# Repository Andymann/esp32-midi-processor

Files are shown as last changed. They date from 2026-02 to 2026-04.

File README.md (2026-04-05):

# esp32-midi-processor

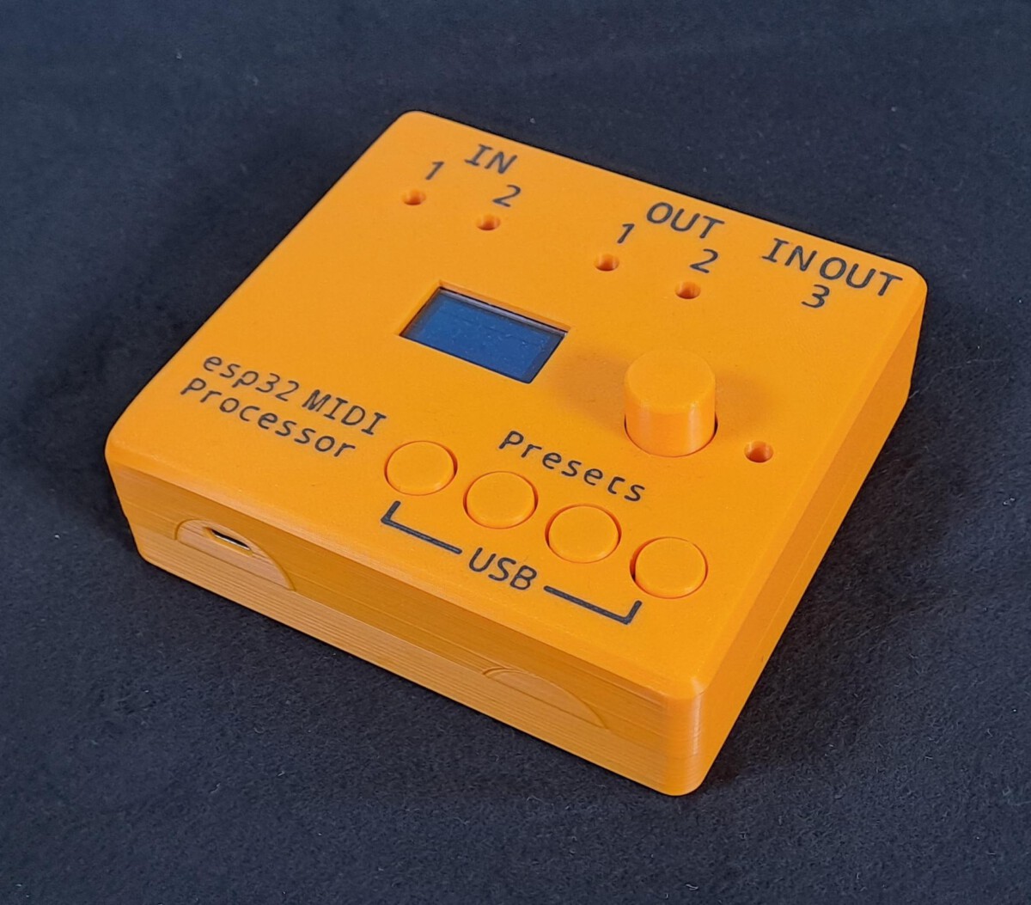
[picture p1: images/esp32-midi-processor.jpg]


esp32-based multitool. Routing, merging, realtime-manipulation of MIDI-data.  
This repo contains code, kicad-files and a BOM for (nearly) one-click order at [pcbway](https://https://pcbway-com).  

Find more details on the project, instructions on how to order your own pcbs and more at https://andyland.info/wordpress/esp32-midi-processor/

If you directly want to order your set of PCBs for this project feel free to

<p style="text-align:center; <a href="https://www.pcbway.com/project/shareproject/esp32_Midi_Prodessor_1403f10f.html">PCB from PCBWay</a></p>

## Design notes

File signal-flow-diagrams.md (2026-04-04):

# ESP32 MIDI Processor — Signal Flow Diagrams

## 1. Top-Level Signal Flow

```mermaid
flowchart LR
    IN1["MIDI In 1\n(Serial1 / UART)"]
    IN2["MIDI In 2\n(Serial2 / UART)"]
    IN3["USB MIDI In\n(MAX3421E Host)"]

    R1["Routing In1\n(None/1/2/3/1+2/1+3/2+3/All)"]
    R2["Routing In2\n(None/1/2/3/1+2/1+3/2+3/All)"]
    R3["Routing In3\n(None/1/2/1+2)"]

    P1["Output 1\nProcessing Pipeline"]
    P2["Output 2\nProcessing Pipeline"]
    P3["USB Output\nProcessing Pipeline"]

    OUT1["MIDI Out 1\n(Serial1 / UART)"]
    OUT2["MIDI Out 2\n(Serial2 / UART)"]
    OUT3["USB MIDI Out\n(MAX3421E Host)"]

    IN1 --> R1
    IN2 --> R2
    IN3 --> R3

    R1 -->|"to Out1"| P1
    R1 -->|"to Out2"| P2
    R1 -->|"to USB"| P3

    R2 -->|"to Out1"| P1
    R2 -->|"to Out2"| P2
    R2 -->|"to USB"| P3

    R3 -->|"to Out1"| P1
    R3 -->|"to Out2"| P2

    P1 --> OUT1
    P2 --> OUT2
    P3 --> OUT3
```

> **Note:** USB In (In3) cannot be routed back to USB Out — only to Out1, Out2, or both.

---

## 2. Per-Output Processing Pipeline

Each of the three outputs has an independent processing pipeline applied to every MIDI message routed to it.

```mermaid
flowchart TD
    A["Incoming MIDI packet\n(from routing)"]
    B["Velocity Modifier\n(passthru / fix 63,100,127 / random / random-100)\nNote On/Off only"]
    C["Note Channel Remap\n(passthru or Ch 1–16)\nNote On/Off only"]
    D["CC Channel Remap\n(passthru or Ch 1–16)\nCC messages only"]
    E["Scale Filter\n(passthru / Major / Minor /\nPentatonic Maj / Pentatonic Min)\nNote On/Off only — drop if out of scale"]
    F["Clock Filter\n(pass all / block clock / clock only)"]
    G{"drop flag set?"}
    H["Send to Output\n(Serial1 / Serial2 / USB)"]
    X["Discard"]

    A --> B --> C --> D --> E --> F --> G
    G -->|"no"| H
    G -->|"yes"| X
```

---

## 3. Routing Options Matrix

Each input has an independent routing setting. The table below lists all values.

```mermaid
flowchart LR
    subgraph "Routing values"
        direction TB
        NONE["None — dropped"]
        TO1["→ Out 1 only"]
        TO2["→ Out 2 only"]
        TO3["→ USB only"]
        TO12["→ Out 1 + Out 2"]
        TO13["→ Out 1 + USB"]
        TO23["→ Out 2 + USB"]
        TO123["→ Out 1 + Out 2 + USB"]
    end

    subgraph "Input 1  (full set)"
        I1(In 1) --> NONE & TO1 & TO2 & TO3 & TO12 & TO13 & TO23 & TO123
    end

    subgraph "Input 2  (full set)"
        I2(In 2) --> NONE2["None"] & TO1b["→ Out 1"] & TO2b["→ Out 2"] & TO3b["→ USB"] & TO12b["→ Out 1+2"] & TO13b["→ Out 1+USB"] & TO23b["→ Out 2+USB"] & TO123b["→ All"]
    end

    subgraph "Input 3 / USB  (limited)"
        I3(USB In) --> NONE3["None"] & TO1c["→ Out 1"] & TO2c["→ Out 2"] & TO12c["→ Out 1+2"]
    end
```

---

## 4. Per-Output Modifier Details

```mermaid
flowchart TD
    subgraph "Velocity  (Note On only)"
        V0[Passthru]
        V1[Fix 63]
        V2[Fix 100]
        V3[Fix 127]
        V4[Random 0–127]
        V5[Random 91–110]
    end

    subgraph "Scale Filter  (Note On/Off only)"
        S0[Passthru — all notes pass]
        S1[Major scale]
        S2[Natural Minor scale]
        S3[Pentatonic Major]
        S4[Pentatonic Minor]
        SN[Root Note: C C# D D# E F F# G G# A A# B]
    end

    subgraph "Channel Remap"
        C0[Note Ch: passthru or 1–16]
        C1[CC Ch: passthru or 1–16]
    end

    subgraph "Clock Filter"
        F0[Pass All — default]
        F1[Block Clock — drop F8/FA/FC]
        F2[Clock Only — pass only F8/FA/FC]
    end
```

---

## 5. MIDI Queue / Processing Order

```mermaid
sequenceDiagram
    participant HW1 as Serial1 (In 1)
    participant HW2 as Serial2 (In 2)
    participant USB as USB MIDI (In 3)
    participant Q  as MIDI Queue (FIFO, 10 slots)
    participant SP as sendPacket()
    participant O1 as Out 1
    participant O2 as Out 2
    participant O3 as USB Out

    loop Every loop()
        HW1->>Q: push (source=1)
        HW2->>Q: push (source=2)
        USB->>Q: push (source=3)
        Q->>SP: pop & process in order
        SP->>SP: apply routing
        SP->>SP: velocity / channel / scale / clock filter (per output)
        SP->>O1: write if routed
        SP->>O2: write if routed
        SP->>O3: send if routed
    end
```

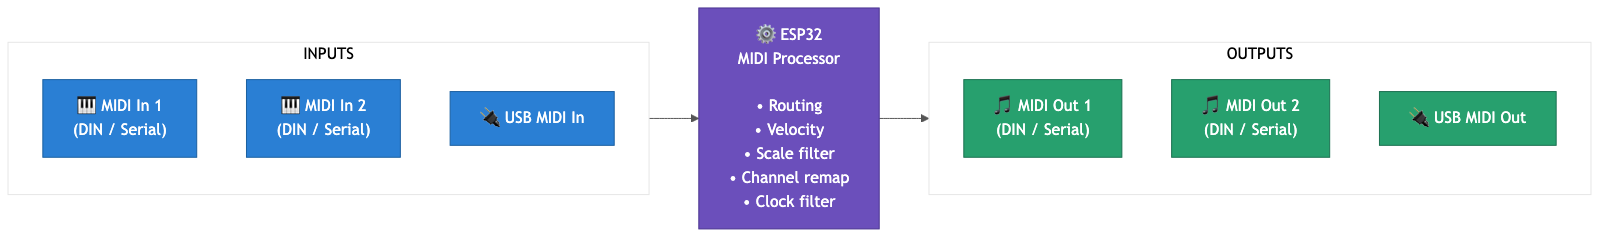
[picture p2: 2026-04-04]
diagrams/simple-01-overview.png

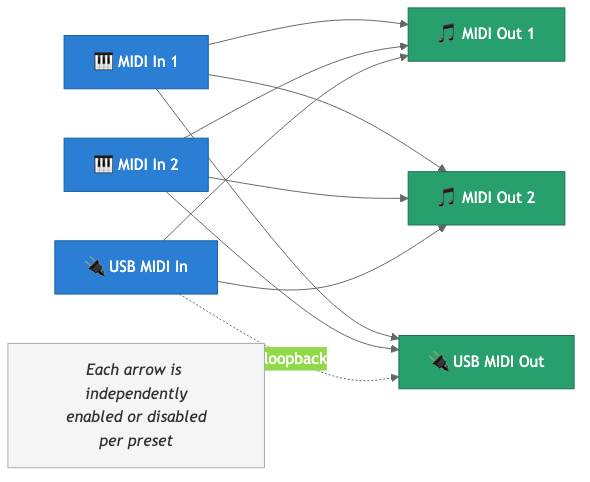
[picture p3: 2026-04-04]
diagrams/simple-02-routing.png

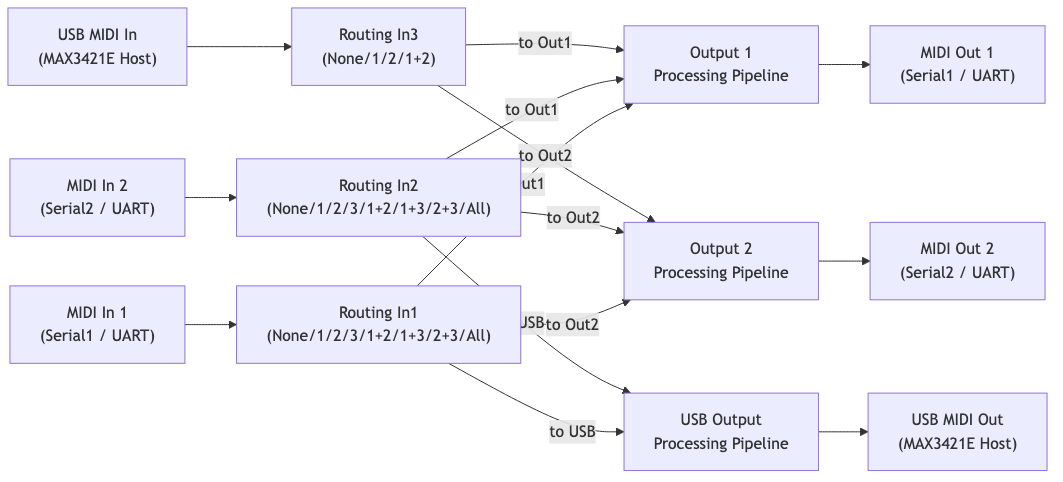
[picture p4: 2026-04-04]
diagrams/01-top-level.png

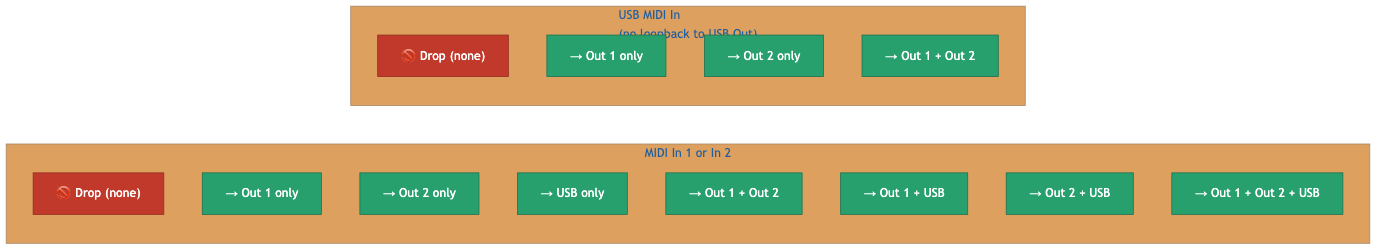
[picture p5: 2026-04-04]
diagrams/simple-04-routing-options.png

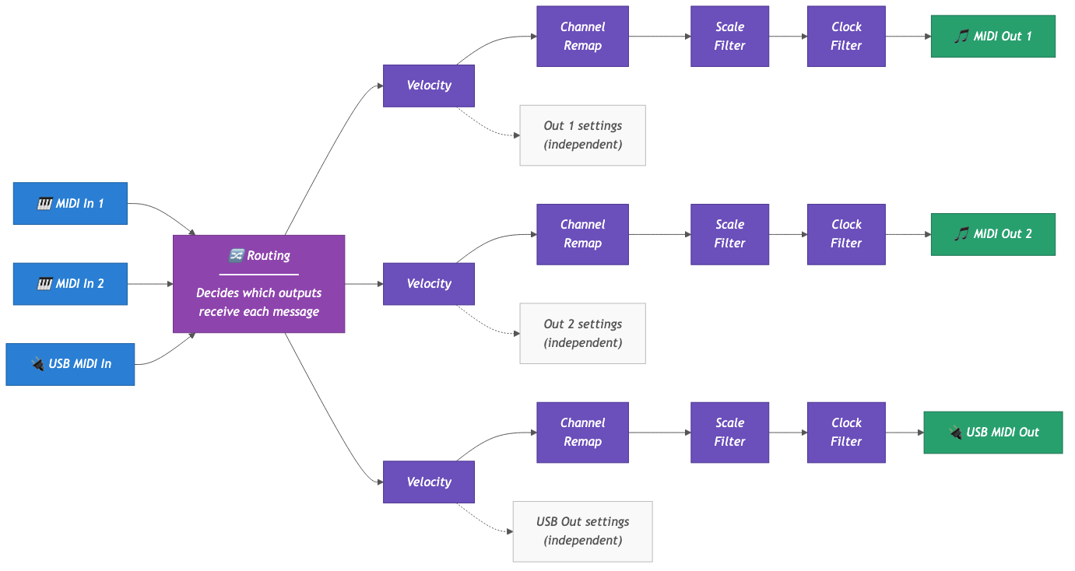
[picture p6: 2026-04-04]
diagrams/simple-05-per-output-processing.png

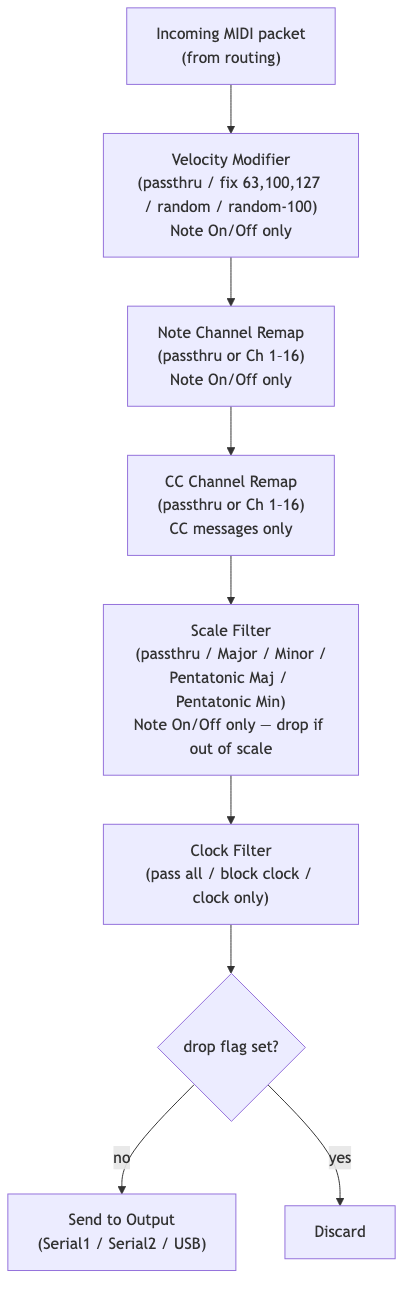
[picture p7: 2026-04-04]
diagrams/02-processing-pipeline.png

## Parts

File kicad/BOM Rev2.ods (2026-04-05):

Item # | *Designator | *Qty | Manufacturer | *Mfg Part # | Description / Value | *Package/Footprint | *Unit Price(5 sets) | *Total | *Delivery Time | *Actual Purchase Mfg Part # | *PCBWay Note | Customer Reply | PCBWay Update
1 | R9,R7 | 2 | Vishay/ Dale | CRCW060333R0JNEA | 33 | R_0603_1608Metric
2 | R3,R6 | 2 | Vishay/ Dale | CRCW06034K70JNEAC | 4k7 | R_0603_1608Metric
3 | R11 | 1 | Vishay/ Dale | CRCW0603330RJNEAC | 330 | R_0603_1608Metric
4 | D5,D4,D3,D7,D6 | 5 | Fetzek | FZ2812-5050 | 2812 addressable RGB LED | LED_SMD:LED_WS2812B_PLCC4_5.0x5.0mm_P3.2mm
5 | R5,R2 | 2 | Vishay/ Dale | CRCW0603470RJNEAC | 470 | R_0603_1608Metric
6 | R15,R16,R14,R12,R13 | 5 | Vishay/ Dale | CRCW060310K0JNEA | 10k | R_0603_1608Metric
7 | C1, C2, C3,C4,C7,C6,C5 | 7 | Kemet | C0603C104K1RACTU | 0.1µ | C_0603_1608Metric
8 | U1,U2 | 2 | Lite-on | 6N138S-TA1 | 6N138
9 | R8,R10 | 2 | Vishay/ Dale | CRCW060310R0JNEA | 10 | R_0603_1608Metric
10 | D1,D2 | 2 | Onsemi | 1N4148WT | 1N4148WT | SOD123
11 | R4,R1 | 2 | Vishay/ Dale | CRCW0603220RJNEAHP | 220 | R_0603_1608Metric
12 | J1, J2, J3, J4 | 4 | CUI Devices | SJ-3523-SMT-TR |  | Jack_3.5mm_CUI_SJ-3523-SMT_Horizontal
13 | J7 | 0 | not used
14 | J12 | 0 | not used
15 | J8 | 0 | not used
16 | J5 | 0 | not used
17 | U3 | 0 | not used
18 | SW5 | 0 | not used
19 | J6 | 0 | not used
20 | J10 | 0 | not used
21 | J13 | 0 | not used
22 | SW2,SW1,SW3,SW4 | 0 | not used
23 | J9 | 0 | not used

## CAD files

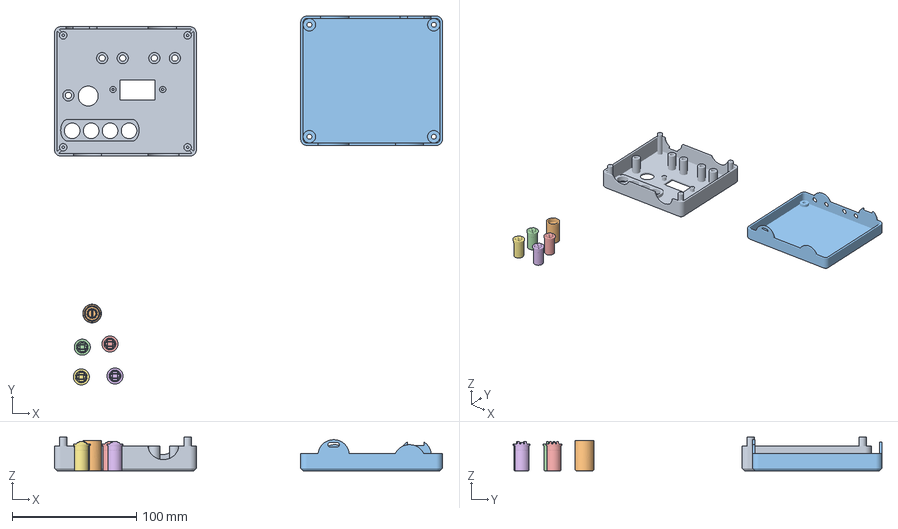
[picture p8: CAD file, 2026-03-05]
esp32 Midi Processor.3mf
311.9 x 296.5 x 27.0 mm
Assembly
esp32 Midi Processor Case Rev 14 Buttons (1).stl
esp32 Midi Processor Case Rev 13.stl
esp32 Midi Processor Case Rev 14 Buttons.stl_1
esp32 Midi Processor Case Rev 14 Buttons.stl_2
esp32 Midi Processor Case Rev 14 Buttons.stl_3
esp32 Midi Processor Case Rev 14 Buttons.stl_4

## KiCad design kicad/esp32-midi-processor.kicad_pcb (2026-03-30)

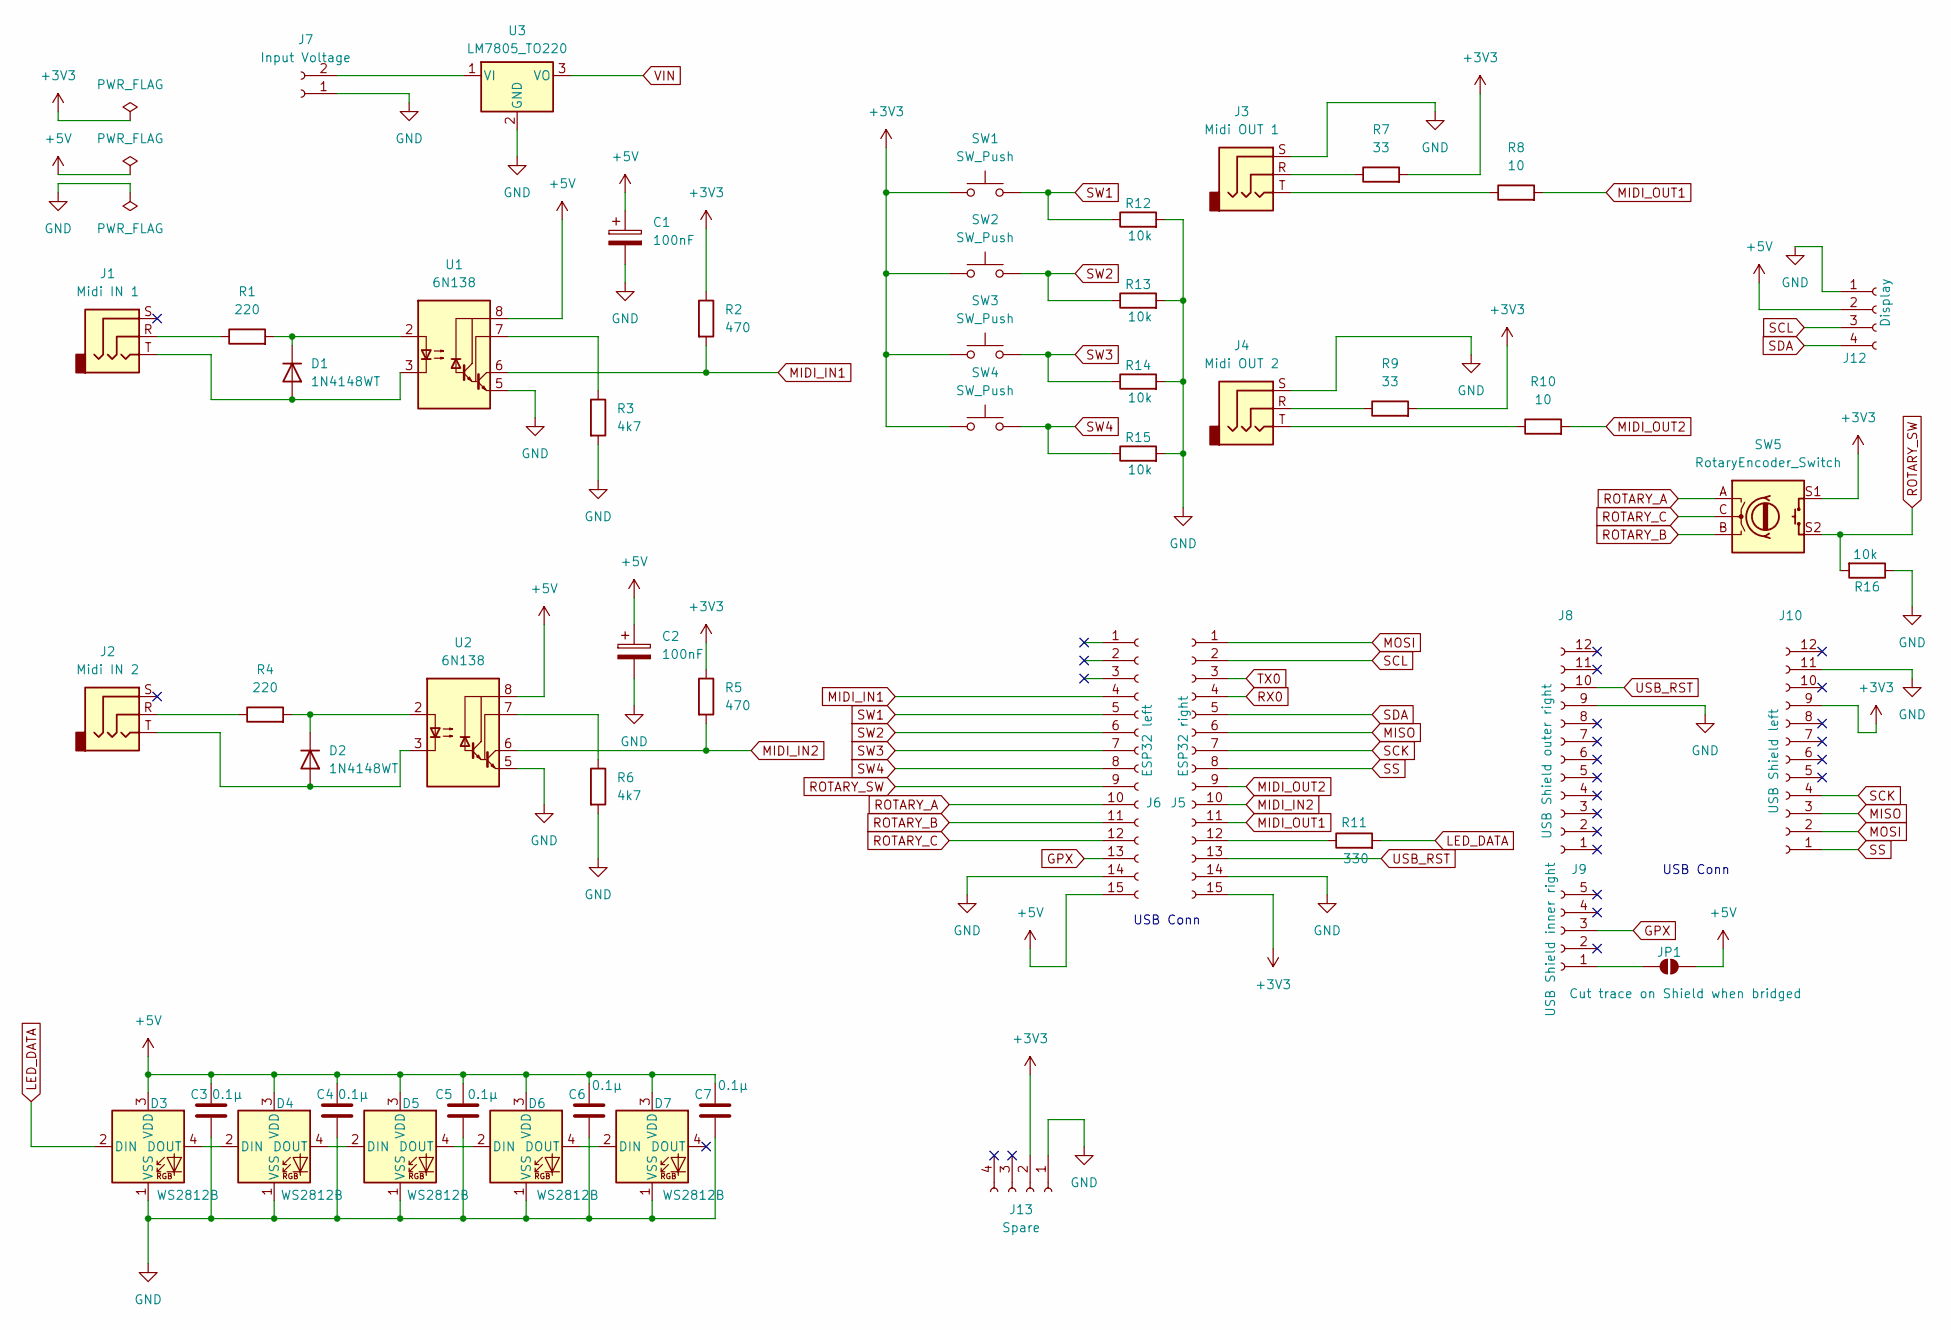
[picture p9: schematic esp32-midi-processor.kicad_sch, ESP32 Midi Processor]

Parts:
C1, C2: 100nF; C_0603_1608Metric
C3, C4, C5, C6, C7: 0.1µ; C_0603_1608Metric
D1, D2: 1N4148WT; D_SOD-523
D3, D4, D5, D6, D7: WS2812B; LED_WS2812B_PLCC4_5.0x5.0mm_P3.2mm
J1: Midi IN 1; Jack_3.5mm_CUI_SJ-3523-SMT_Horizontal
J2: Midi IN 2; Jack_3.5mm_CUI_SJ-3523-SMT_Horizontal
J3: Midi OUT 1; Jack_3.5mm_CUI_SJ-3523-SMT_Horizontal
J4: Midi OUT 2; Jack_3.5mm_CUI_SJ-3523-SMT_Horizontal
J5: ESP32 right; PinHeader_1x15_P2.54mm_Vertical
J6: ESP32 left; PinHeader_1x15_P2.54mm_Vertical
J7: Input Voltage; TerminalBlock_RND_205-00001_1x02_P5.00mm_Horizontal
J8: USB Shield outer right; PinHeader_1x12_P2.54mm_Vertical
J9: USB Shield inner right; PinHeader_1x05_P2.54mm_Vertical
J10: USB Shield left; PinHeader_1x12_P2.54mm_Vertical
J12: Display; PinHeader_1x04_P2.54mm_Vertical
J13: Spare; PinHeader_1x04_P2.54mm_Vertical
JP1: Cut trace on Shield when bridged; SolderJumper-2_P1.3mm_Open_RoundedPad1.0x1.5mm
R1, R4: 220; R_0603_1608Metric
R2, R5: 470; R_0603_1608Metric
R3, R6: 4k7; R_0603_1608Metric
R7, R9: 33; R_0603_1608Metric
R8, R10: 10; R_0603_1608Metric
R11: 330; R_0603_1608Metric
R12, R13, R14, R15, R16: 10k; R_0603_1608Metric
SW1, SW2, SW3, SW4: SW_Push; SW_PUSH-12mm_Wuerth-430476085716
SW5: RotaryEncoder_Switch; RotaryEncoder_Alps_EC11E-Switch_Vertical_H20mm
U1, U2: 6N138; SOP-8_6.605x9.655mm_P2.54mm
U3: LM7805_TO220; TO-220-3_Vertical

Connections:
+3V3: J5.15, J10.9, J13.2, R2.1, R5.1, R7.2, R9.2, SW1.1, SW2.1, SW3.1, SW4.1, SW5.S1
+5V: C1.1, C2.1, C3.1, C4.1, C5.1, C6.1, C7.1, D3.3 (VDD), D4.3 (VDD), D5.3 (VDD), D6.3 (VDD), D7.3 (VDD), J6.15, J12.2, JP1.2 (B), U1.8 (VCC), U2.8 (VCC)
GND: C1.2, C2.2, C3.2, C4.2, C5.2, C6.2, C7.2, D3.1 (VSS), D4.1 (VSS), D5.1 (VSS), D6.1 (VSS), D7.1 (VSS), J3.S, J4.S, J5.14, J6.14, J7.1, J8.9, J10.11, J12.1, J13.1, R3.2, R6.2, R12.2, R13.2, R14.2, R15.2, R16.1, U1.5 (GND), U2.5 (GND), U3.2 (GND)
GPX: J6.13, J9.3
LED_DATA: D3.2 (DIN), R11.2
MIDI_IN1: J6.4, R2.2, U1.6 (VO2)
MIDI_IN2: J5.10, R5.2, U2.6 (VO2)
MIDI_OUT1: J5.11, R8.2
MIDI_OUT2: J5.9, R10.2
MISO: J5.6, J10.3
MOSI: J5.1, J10.2
unnamed: D1.2 (A), J1.T, U1.3 (C2)
unnamed: D1.1 (K), R1.2, U1.2 (C1)
unnamed: D2.2 (A), J2.T, U2.3 (C2)
unnamed: D2.1 (K), R4.2, U2.2 (C1)
unnamed: D3.4 (DOUT), D4.2 (DIN)
unnamed: D4.4 (DOUT), D5.2 (DIN)
unnamed: D5.4 (DOUT), D6.2 (DIN)
unnamed: D6.4 (DOUT), D7.2 (DIN)
unnamed: J1.R, R1.1
unnamed: J2.R, R4.1
unnamed: J3.R, R7.1
unnamed: J3.T, R8.1
unnamed: J4.R, R9.1
unnamed: J4.T, R10.1
unnamed: J5.12, R11.1
unnamed: J7.2, U3.1 (VI)
unnamed: J9.1, JP1.1 (A)
unnamed: R3.1, U1.7 (VO1)
unnamed: R6.1, U2.7 (VO1)
ROTARY_A: J6.10, SW5.A
ROTARY_B: J6.11, SW5.B
ROTARY_C: J6.12, SW5.C
ROTARY_SW: J6.9, R16.2, SW5.S2
RX0: J5.4
SCK: J5.7, J10.4
SCL: J5.2, J12.3
SDA: J5.5, J12.4
SS: J5.8, J10.1
SW1: J6.5, R12.1, SW1.2
SW2: J6.6, R13.1, SW2.2
SW3: J6.7, R14.1, SW3.2
SW4: J6.8, R15.1, SW4.2
TX0: J5.3
USB_RST: J5.13, J8.10
VIN: U3.3 (VO)

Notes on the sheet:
USB Conn

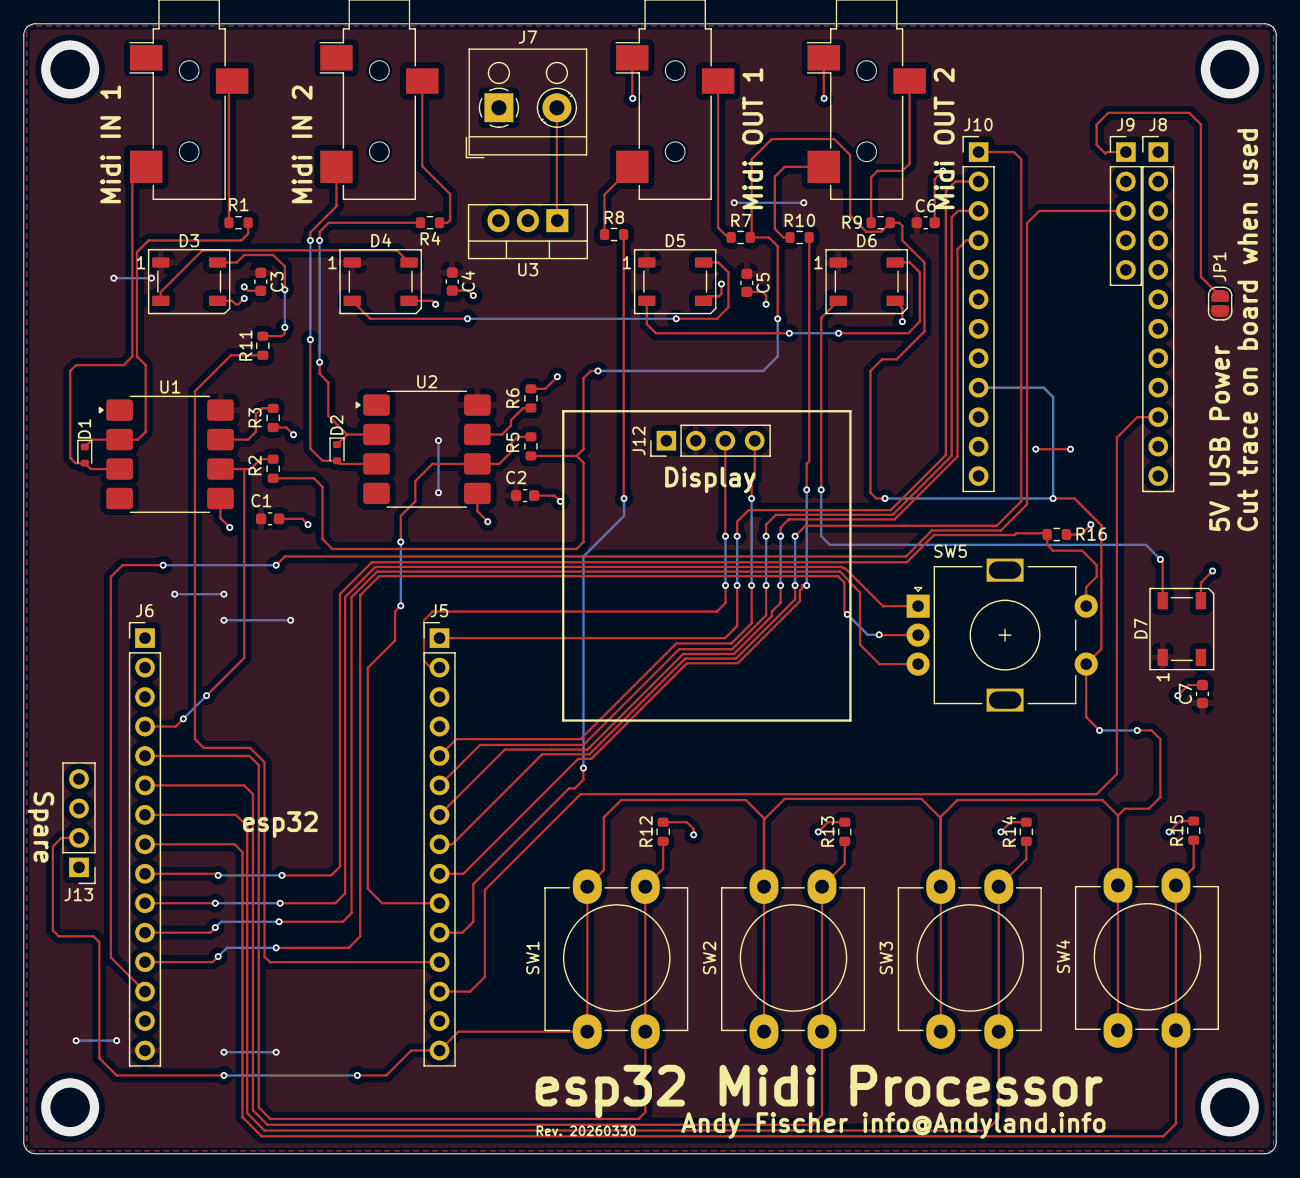
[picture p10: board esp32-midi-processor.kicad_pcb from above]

Board: 2 copper layers, 108.0 x 97.4 mm, 51 parts (0 on the bottom side), 43 nets.

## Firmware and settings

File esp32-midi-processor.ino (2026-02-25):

/*
    esp32 Midi Processor
*/
#include <HardwareSerial.h>
#include <Adafruit_NeoPixel.h>
#include <SPI.h>
#include <Wire.h>
#include <Adafruit_GFX.h>
#include <Adafruit_SSD1306.h>
#include <ESP32Encoder.h> // https://github.com/madhephaestus/ESP32Encoder.git 
#include <usbh_midi.h>
#include <usbhub.h>
#include <AbleButtons.h>
#include "AppFeature.h"
#include <Fonts/FreeSans9pt7b.h>
#include <Fonts/FreeSans24pt7b.h>
#include <BlockNot.h>
#include <EEPROM.h>

#define VERSION "0.98"

#define PRESET_COUNT 4
#define EEPROM_SIZE  (2 + PRESET_COUNT * (1 + sizeof(AppSettings)))

// Declaration for SSD1306 display connected using I2C
#define SCREEN_WIDTH 128  // OLED display width, in pixels
#define SCREEN_HEIGHT 64  // OLED display height, in pixels
#define OLED_RESET -1  // Reset pin # (or -1 if sharing Arduino reset pin)
#define SCREEN_ADDRESS 0x3C
Adafruit_SSD1306 display(SCREEN_WIDTH, SCREEN_HEIGHT, &Wire, OLED_RESET);

#define NUM_LEDS 5
#define LED_DATA_PIN 2
#define LED_OFF 0
#define LED_ON 10
Adafruit_NeoPixel pixels(NUM_LEDS, LED_DATA_PIN, NEO_GRB + NEO_KHZ800);

// Serial
#define RXD2 16
#define TXD2 17
#define TXD1 4
#define RXD1 34

// Rotary
#define CLK 14 // CLK ENCODER 
#define ENC_C 27
#define DT 12 // DT ENCODER 
ESP32Encoder encoder;
int64_t iEncoderLast=0;

#define MIDI_CLOCK 0xF8
#define MIDI_START 0xFA
#define MIDI_STOP 0xFC

// USB
USB Usb;
USBHub Hub(&Usb);
USBH_MIDI  Midi(&Usb);
#define MAX_RESET 15 //MAX3421E pin 12
#define MAX_GPX   13 //MAX3421E pin 17


using Button = AblePulldownClickerButton;

Button btnA(35);
Button btnB(32);
Button btnC(33);
Button btnD(25);
Button btnEnc(26);

BlockNot tmrIn1(50); //In Milliseconds 
BlockNot tmrIn2(50);
BlockNot tmrOut1(50);
BlockNot tmrOut2(50);
BlockNot tmrUSB(50);
BlockNot tmrDisplay(3000);

bool bBtnA_Reset = false;
bool bBtnB_Reset = false;
bool bBtnC_Reset = false;
bool bBtnD_Reset = false;
bool bBtnEnc_Reset = false;

bool bBtnA_old = false;
bool bBtnB_old = false;
bool bBtnC_old = false;
bool bBtnD_old = false;
bool bBtnEnc_old = false;

bool btnA_Held = false;
bool btnB_Held = false;
bool btnC_Held = false;
bool btnD_Held = false;
bool btnEnc_Held = false;
bool bBtnAD_ComboActive = false;  // A+D held: skip preset save, allow Usb.Init 
// Input packet with data and drop flag (replaces using 3rd byte 0xFF as sentinel)
struct MidiPacket {
  uint8_t data[3];
  bool drop;  // true = no data / do not send (filtered or already consumed)
};

// Queue: up to 10 incoming MIDI events, processed in order (FIFO)
#define MIDI_QUEUE_SIZE 10
struct QueuedMidiEvent {
  MidiPacket pkt;
  uint8_t source;  // 1, 2, or 3 for input 1, 2, USB
};
static QueuedMidiEvent midiQueue[MIDI_QUEUE_SIZE];
static uint8_t queueHead = 0;  // next write
static uint8_t queueTail = 0;  // next read
static uint8_t queueCount = 0;

static bool pushMidiQueue(const MidiPacket *pkt, uint8_t source) {
  if (queueCount >= MIDI_QUEUE_SIZE) return false;
  midiQueue[queueHead].pkt = *pkt;
  midiQueue[queueHead].pkt.drop = false;
  midiQueue[queueHead].source = source;
  queueHead = (queueHead + 1) % MIDI_QUEUE_SIZE;
  queueCount++;
  return true;
}
static bool popMidiQueue(QueuedMidiEvent *out) {
  if (queueCount == 0) return false;
  *out = midiQueue[queueTail];
  queueTail = (queueTail + 1) % MIDI_QUEUE_SIZE;
  queueCount--;
  return true;
}

MidiPacket midiPacket_IN1 = { {0xFF, 0xFF, 0xFF}, true };
MidiPacket midiPacket_IN2 = { {0xFF, 0xFF, 0xFF}, true };
MidiPacket midiPacket_IN3 = { {0xFF, 0xFF, 0xFF}, true };
uint8_t iCounter_IN1 = 0;
uint8_t iCounter_IN2 = 0;


AppFeature arrFeatures[] = {
  AppFeature("Route 1-x", 0, FEATURE_GROUP_ROUTING_IN_1, ROUTING_TO_NONE),
  AppFeature("Route 1-1", 0, FEATURE_GROUP_ROUTING_IN_1, ROUTING_TO_1, true),
  AppFeature("Route 1-2", 0, FEATURE_GROUP_ROUTING_IN_1, ROUTING_TO_2),
  AppFeature("Route 1-3", 0, FEATURE_GROUP_ROUTING_IN_1, ROUTING_TO_3),
  AppFeature("Route 1-1,2", 0, FEATURE_GROUP_ROUTING_IN_1, ROUTING_TO_12),
  AppFeature("Route 1-1,3", 0, FEATURE_GROUP_ROUTING_IN_1, ROUTING_TO_13),
  AppFeature("Route 1-2,3", 0, FEATURE_GROUP_ROUTING_IN_1, ROUTING_TO_23),
  AppFeature("Route 1-All", 0, FEATURE_GROUP_ROUTING_IN_1, ROUTING_TO_123),

  AppFeature("Route 2-x", 0, FEATURE_GROUP_ROUTING_IN_2, ROUTING_TO_NONE, true),
  AppFeature("Route 2-1", 0, FEATURE_GROUP_ROUTING_IN_2, ROUTING_TO_1),
  AppFeature("Route 2-2", 0, FEATURE_GROUP_ROUTING_IN_2, ROUTING_TO_2),
  AppFeature("Route 2-3", 0, FEATURE_GROUP_ROUTING_IN_2, ROUTING_TO_3),
  AppFeature("Route 2-1,2", 0, FEATURE_GROUP_ROUTING_IN_2, ROUTING_TO_12),
  AppFeature("Route 2-1,3", 0, FEATURE_GROUP_ROUTING_IN_2, ROUTING_TO_13),
  AppFeature("Route 2-2,3", 0, FEATURE_GROUP_ROUTING_IN_2, ROUTING_TO_23),
  AppFeature("Route 2-All", 0, FEATURE_GROUP_ROUTING_IN_2, ROUTING_TO_123),

  AppFeature("Route 3-x", 0, FEATURE_GROUP_ROUTING_IN_3, ROUTING_TO_NONE, true),
  AppFeature("Route 3-1", 0, FEATURE_GROUP_ROUTING_IN_3, ROUTING_TO_1),
  AppFeature("Route 3-2", 0, FEATURE_GROUP_ROUTING_IN_3, ROUTING_TO_2),
  //AppFeature("Route 3-3", 0, FEATURE_GROUP_ROUTING_IN_3, ROUTING_3_TO_3),
  AppFeature("Route 3-1,2", 0, FEATURE_GROUP_ROUTING_IN_3, ROUTING_TO_12),
  //AppFeature("Route 3-1,3", 0, FEATURE_GROUP_ROUTING_IN_3, ROUTING_3_TO_13),
  //AppFeature("Route 3-2,3", 0, FEATURE_GROUP_ROUTING_IN_3, ROUTING_3_TO_23),
  //AppFeature("Route 3-All", 0, FEATURE_GROUP_ROUTING_IN_3, ROUTING_3_TO_123),

  AppFeature("1 Vel PT", 1, FEATURE_GROUP_VELOCITY, VELOCITY_PASSTHRU, true),
  AppFeature("1 Vel Fix63", 1, FEATURE_GROUP_VELOCITY, VELOCITY_FIX_63),
  AppFeature("1 Vel Fix100", 1, FEATURE_GROUP_VELOCITY, VELOCITY_FIX_100),
  AppFeature("1 Vel Fix127", 1, FEATURE_GROUP_VELOCITY, VELOCITY_FIX_127),
  AppFeature("1 Vel Rnd", 1, FEATURE_GROUP_VELOCITY, VELOCITY_RANDOM),
  AppFeature("1 Vel Rnd100", 1, FEATURE_GROUP_VELOCITY, VELOCITY_RANDOM_100),

  AppFeature("1 Scale PT", 1, FEATURE_GROUP_SCALE, SCALE_PASSTHRU, true),
  AppFeature("1 Scale Maj", 1, FEATURE_GROUP_SCALE, SCALE_MAJOR),
  AppFeature("1 Scale Min", 1, FEATURE_GROUP_SCALE, SCALE_MINOR),
  AppFeature("1 Scale 5Maj", 1, FEATURE_GROUP_SCALE, SCALE_PENTATONIC_MAJOR),
  AppFeature("1 Scale 5Min", 1, FEATURE_GROUP_SCALE, SCALE_PENTATONIC_MINOR),

  AppFeature("1 Root None", 1, FEATURE_GROUP_ROOTNOTE, ROOTNOTE_PASSTHROUGH, true),
  AppFeature("1 Root C", 1, FEATURE_GROUP_ROOTNOTE, ROOTNOTE_C),
  AppFeature("1 Root C#", 1, FEATURE_GROUP_ROOTNOTE, ROOTNOTE_Cs),
  AppFeature("1 Root D", 1, FEATURE_GROUP_ROOTNOTE, ROOTNOTE_D),
  AppFeature("1 Root D#", 1, FEATURE_GROUP_ROOTNOTE, ROOTNOTE_Ds),
  AppFeature("1 Root E", 1, FEATURE_GROUP_ROOTNOTE, ROOTNOTE_E),
  AppFeature("1 Root F", 1, FEATURE_GROUP_ROOTNOTE, ROOTNOTE_F),
  AppFeature("1 Root F#", 1, FEATURE_GROUP_ROOTNOTE, ROOTNOTE_Fs),
  AppFeature("1 Root G", 1, FEATURE_GROUP_ROOTNOTE, ROOTNOTE_G),
  AppFeature("1 Root G#", 1, FEATURE_GROUP_ROOTNOTE, ROOTNOTE_Gs),
  AppFeature("1 Root A", 1, FEATURE_GROUP_ROOTNOTE, ROOTNOTE_A),
  AppFeature("1 Root A#", 1, FEATURE_GROUP_ROOTNOTE, ROOTNOTE_As),
  AppFeature("1 Root H", 1, FEATURE_GROUP_ROOTNOTE, ROOTNOTE_H),

  AppFeature("1 Note Ch PT", 1, FEATURE_GROUP_NOTE_CHANNEL, CHANNEL_PASSTHRU, true),
  AppFeature("1 Note Ch 1", 1, FEATURE_GROUP_NOTE_CHANNEL, CHANNEL_1),
  AppFeature("1 Note Ch 2", 1, FEATURE_GROUP_NOTE_CHANNEL, CHANNEL_2),
  AppFeature("1 Note Ch 3", 1, FEATURE_GROUP_NOTE_CHANNEL, CHANNEL_3),
  AppFeature("1 Note Ch 4", 1, FEATURE_GROUP_NOTE_CHANNEL, CHANNEL_4),
  AppFeature("1 Note Ch 5", 1, FEATURE_GROUP_NOTE_CHANNEL, CHANNEL_5),
  AppFeature("1 Note Ch 6", 1, FEATURE_GROUP_NOTE_CHANNEL, CHANNEL_6),
  AppFeature("1 Note Ch 7", 1, FEATURE_GROUP_NOTE_CHANNEL, CHANNEL_7),
  AppFeature("1 Note Ch 8", 1, FEATURE_GROUP_NOTE_CHANNEL, CHANNEL_8),
  AppFeature("1 Note Ch 9", 1, FEATURE_GROUP_NOTE_CHANNEL, CHANNEL_9),
  AppFeature("1 Note Ch 10", 1, FEATURE_GROUP_NOTE_CHANNEL, CHANNEL_10),
  AppFeature("1 Note Ch 11", 1, FEATURE_GROUP_NOTE_CHANNEL, CHANNEL_11),
  AppFeature("1 Note Ch 12", 1, FEATURE_GROUP_NOTE_CHANNEL, CHANNEL_12),
  AppFeature("1 Note Ch 13", 1, FEATURE_GROUP_NOTE_CHANNEL, CHANNEL_13),
  AppFeature("1 Note Ch 14", 1, FEATURE_GROUP_NOTE_CHANNEL, CHANNEL_14),
  AppFeature("1 Note Ch 15", 1, FEATURE_GROUP_NOTE_CHANNEL, CHANNEL_15),
  AppFeature("1 Note Ch 16", 1, FEATURE_GROUP_NOTE_CHANNEL, CHANNEL_16),

  AppFeature("1 CC Ch PT", 1, FEATURE_GROUP_CC_CHANNEL, CHANNEL_PASSTHRU, true),
  AppFeature("1 CC Ch 1", 1, FEATURE_GROUP_CC_CHANNEL, CHANNEL_1),
  AppFeature("1 CC Ch 2", 1, FEATURE_GROUP_CC_CHANNEL, CHANNEL_2),
  AppFeature("1 CC Ch 3", 1, FEATURE_GROUP_CC_CHANNEL, CHANNEL_3),
  AppFeature("1 CC Ch 4", 1, FEATURE_GROUP_CC_CHANNEL, CHANNEL_4),
  AppFeature("1 CC Ch 5", 1, FEATURE_GROUP_CC_CHANNEL, CHANNEL_5),
  AppFeature("1 CC Ch 6", 1, FEATURE_GROUP_CC_CHANNEL, CHANNEL_6),
  AppFeature("1 CC Ch 7", 1, FEATURE_GROUP_CC_CHANNEL, CHANNEL_7),
  AppFeature("1 CC Ch 8", 1, FEATURE_GROUP_CC_CHANNEL, CHANNEL_8),
  AppFeature("1 CC Ch 9", 1, FEATURE_GROUP_CC_CHANNEL, CHANNEL_9),
  AppFeature("1 CC Ch 10", 1, FEATURE_GROUP_CC_CHANNEL, CHANNEL_10),
  AppFeature("1 CC Ch 11", 1, FEATURE_GROUP_CC_CHANNEL, CHANNEL_11),
  AppFeature("1 CC Ch 12", 1, FEATURE_GROUP_CC_CHANNEL, CHANNEL_12),
  AppFeature("1 CC Ch 13", 1, FEATURE_GROUP_CC_CHANNEL, CHANNEL_13),
  AppFeature("1 CC Ch 14", 1, FEATURE_GROUP_CC_CHANNEL, CHANNEL_14),
  AppFeature("1 CC Ch 15", 1, FEATURE_GROUP_CC_CHANNEL, CHANNEL_15),
  AppFeature("1 CC Ch 16", 1, FEATURE_GROUP_CC_CHANNEL, CHANNEL_16),

  AppFeature("2 Vel PT", 2, FEATURE_GROUP_VELOCITY, VELOCITY_PASSTHRU, true),
  AppFeature("2 Vel Fix63", 2, FEATURE_GROUP_VELOCITY, VELOCITY_FIX_63),
  AppFeature("2 Vel Fix100", 2, FEATURE_GROUP_VELOCITY, VELOCITY_FIX_100),
  AppFeature("2 Vel Fix127", 2, FEATURE_GROUP_VELOCITY, VELOCITY_FIX_127),
  AppFeature("2 Vel Rnd", 2, FEATURE_GROUP_VELOCITY, VELOCITY_RANDOM),
  AppFeature("2 Vel Rnd100", 2, FEATURE_GROUP_VELOCITY, VELOCITY_RANDOM_100),

  AppFeature("2 Scale PT", 2, FEATURE_GROUP_SCALE, SCALE_PASSTHRU, true),
  AppFeature("2 Scale Maj", 2, FEATURE_GROUP_SCALE, SCALE_MAJOR),
  AppFeature("2 Scale Min", 2, FEATURE_GROUP_SCALE, SCALE_MINOR),
  AppFeature("2 Scale 5Maj", 2, FEATURE_GROUP_SCALE, SCALE_PENTATONIC_MAJOR),
  AppFeature("2 Scale 5Min", 2, FEATURE_GROUP_SCALE, SCALE_PENTATONIC_MINOR),

  AppFeature("2 Root None", 2, FEATURE_GROUP_ROOTNOTE, ROOTNOTE_PASSTHROUGH, true),
  AppFeature("2 Root C", 2, FEATURE_GROUP_ROOTNOTE, ROOTNOTE_C),
  AppFeature("2 Root C#", 2, FEATURE_GROUP_ROOTNOTE, ROOTNOTE_Cs),
  AppFeature("2 Root D", 2, FEATURE_GROUP_ROOTNOTE, ROOTNOTE_D),
  AppFeature("2 Root D#", 2, FEATURE_GROUP_ROOTNOTE, ROOTNOTE_Ds),
  AppFeature("2 Root E", 2, FEATURE_GROUP_ROOTNOTE, ROOTNOTE_E),
  AppFeature("2 Root F", 2, FEATURE_GROUP_ROOTNOTE, ROOTNOTE_F),
  AppFeature("2 Root F#", 2, FEATURE_GROUP_ROOTNOTE, ROOTNOTE_Fs),
  AppFeature("2 Root G", 2, FEATURE_GROUP_ROOTNOTE, ROOTNOTE_G),
  AppFeature("2 Root G#", 2, FEATURE_GROUP_ROOTNOTE, ROOTNOTE_Gs),
  AppFeature("2 Root A", 2, FEATURE_GROUP_ROOTNOTE, ROOTNOTE_A),
  AppFeature("2 Root A#", 2, FEATURE_GROUP_ROOTNOTE, ROOTNOTE_As),
  AppFeature("2 Root H", 2, FEATURE_GROUP_ROOTNOTE, ROOTNOTE_H),

  AppFeature("2 Note Ch PT", 2, FEATURE_GROUP_NOTE_CHANNEL, CHANNEL_PASSTHRU, true),
  AppFeature("2 Note Ch 1", 2, FEATURE_GROUP_NOTE_CHANNEL, CHANNEL_1),
  AppFeature("2 Note Ch 2", 2, FEATURE_GROUP_NOTE_CHANNEL, CHANNEL_2),
  AppFeature("2 Note Ch 3", 2, FEATURE_GROUP_NOTE_CHANNEL, CHANNEL_3),
  AppFeature("2 Note Ch 4", 2, FEATURE_GROUP_NOTE_CHANNEL, CHANNEL_4),
  AppFeature("2 Note Ch 5", 2, FEATURE_GROUP_NOTE_CHANNEL, CHANNEL_5),
  AppFeature("2 Note Ch 6", 2, FEATURE_GROUP_NOTE_CHANNEL, CHANNEL_6),
  AppFeature("2 Note Ch 7", 2, FEATURE_GROUP_NOTE_CHANNEL, CHANNEL_7),
  AppFeature("2 Note Ch 8", 2, FEATURE_GROUP_NOTE_CHANNEL, CHANNEL_8),
  AppFeature("2 Note Ch 9", 2, FEATURE_GROUP_NOTE_CHANNEL, CHANNEL_9),
  AppFeature("2 Note Ch 10", 2, FEATURE_GROUP_NOTE_CHANNEL, CHANNEL_10),
  AppFeature("2 Note Ch 11", 2, FEATURE_GROUP_NOTE_CHANNEL, CHANNEL_11),
  AppFeature("2 Note Ch 12", 2, FEATURE_GROUP_NOTE_CHANNEL, CHANNEL_12),
  AppFeature("2 Note Ch 13", 2, FEATURE_GROUP_NOTE_CHANNEL, CHANNEL_13),
  AppFeature("2 Note Ch 14", 2, FEATURE_GROUP_NOTE_CHANNEL, CHANNEL_14),
  AppFeature("2 Note Ch 15", 2, FEATURE_GROUP_NOTE_CHANNEL, CHANNEL_15),
  AppFeature("2 Note Ch 16", 2, FEATURE_GROUP_NOTE_CHANNEL, CHANNEL_16),

  AppFeature("2 CC Ch PT", 2, FEATURE_GROUP_CC_CHANNEL, CHANNEL_PASSTHRU, true),
  AppFeature("2 CC Ch 1", 2, FEATURE_GROUP_CC_CHANNEL, CHANNEL_1),
  AppFeature("2 CC Ch 2", 2, FEATURE_GROUP_CC_CHANNEL, CHANNEL_2),
  AppFeature("2 CC Ch 3", 2, FEATURE_GROUP_CC_CHANNEL, CHANNEL_3),
  AppFeature("2 CC Ch 4", 2, FEATURE_GROUP_CC_CHANNEL, CHANNEL_4),
  AppFeature("2 CC Ch 5", 2, FEATURE_GROUP_CC_CHANNEL, CHANNEL_5),
  AppFeature("2 CC Ch 6", 2, FEATURE_GROUP_CC_CHANNEL, CHANNEL_6),
  AppFeature("2 CC Ch 7", 2, FEATURE_GROUP_CC_CHANNEL, CHANNEL_7),
  AppFeature("2 CC Ch 8", 2, FEATURE_GROUP_CC_CHANNEL, CHANNEL_8),
  AppFeature("2 CC Ch 9", 2, FEATURE_GROUP_CC_CHANNEL, CHANNEL_9),
  AppFeature("2 CC Ch 10", 2, FEATURE_GROUP_CC_CHANNEL, CHANNEL_10),
  AppFeature("2 CC Ch 11", 2, FEATURE_GROUP_CC_CHANNEL, CHANNEL_11),
  AppFeature("2 CC Ch 12", 2, FEATURE_GROUP_CC_CHANNEL, CHANNEL_12),
  AppFeature("2 CC Ch 13", 2, FEATURE_GROUP_CC_CHANNEL, CHANNEL_13),
  AppFeature("2 CC Ch 14", 2, FEATURE_GROUP_CC_CHANNEL, CHANNEL_14),
  AppFeature("2 CC Ch 15", 2, FEATURE_GROUP_CC_CHANNEL, CHANNEL_15),
  AppFeature("2 CC Ch 16", 2, FEATURE_GROUP_CC_CHANNEL, CHANNEL_16),

  AppFeature("3 Vel PT", 3, FEATURE_GROUP_VELOCITY, VELOCITY_PASSTHRU, true),
  AppFeature("3 Vel Fix63", 3, FEATURE_GROUP_VELOCITY, VELOCITY_FIX_63),
  AppFeature("3 Vel Fix100", 3, FEATURE_GROUP_VELOCITY, VELOCITY_FIX_100),
  AppFeature("3 Vel Fix127", 3, FEATURE_GROUP_VELOCITY, VELOCITY_FIX_127),
  AppFeature("3 Vel Rnd", 3, FEATURE_GROUP_VELOCITY, VELOCITY_RANDOM),
  AppFeature("3 Vel Rnd100", 3, FEATURE_GROUP_VELOCITY, VELOCITY_RANDOM_100),
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
void loop() {
  Usb.Task();
  if ( Midi ) {
    uint8_t size;
    do {
      size = Midi.RecvData(midiPacket_IN3.data);
      if (size > 0) {
        midiPacket_IN3.drop = false;
        pushMidiQueue(&midiPacket_IN3, 3);  // USB = source 3; passed through based on routing
        pixels.setPixelColor(4, pixels.Color(LED_ON, LED_ON, LED_OFF));
        pixels.show();
        tmrUSB.RESET;
      }
    } while (size > 0);
  }

  // encoder.attachFullQuad() provides bes results but counts 2 steps on one click, 
  // so we only count every 2nd step
  if(encoder.getCount()<iEncoderLast-1){
    processMenuNavigation( -1 );
    iEncoderLast=encoder.getCount();
  }
  
  if(encoder.getCount()>iEncoderLast+1){
    processMenuNavigation( +1 );
    iEncoderLast=encoder.getCount();
  }

  readData();

  checkButton_Combo();  // A+D long press = Usb.Init; must run before A/D handlers
  checkButton_A();
  checkButton_B();
  checkButton_C();
  checkButton_D();
  checkButton_Enc();

  if (tmrIn1.FIRST_TRIGGER){ 
    pixels.setPixelColor(0, pixels.Color(LED_OFF, LED_OFF, LED_OFF));
    pixels.show();
  }  

  if (tmrIn2.FIRST_TRIGGER){ 
    pixels.setPixelColor(1, pixels.Color(LED_OFF, LED_OFF, LED_OFF));
    pixels.show();
  }  

  if (tmrOut1.FIRST_TRIGGER){ 
    pixels.setPixelColor(2, pixels.Color(LED_OFF, LED_OFF, LED_OFF));
    pixels.show();
  }  

  if (tmrOut2.FIRST_TRIGGER){ 
    pixels.setPixelColor(3, pixels.Color(LED_OFF, LED_OFF, LED_OFF));
    pixels.show();
  }  

  if (tmrUSB.FIRST_TRIGGER){ 
    pixels.setPixelColor(4, pixels.Color(LED_OFF, LED_OFF, LED_OFF));
    pixels.show();
  }  

  // Re-show display after loading or storing a preset
  if(tmrDisplay.FIRST_TRIGGER){
    displayText(getMenuItem(iMenuPosition), getMenuItem(iMenuPosition + 1), getMenuItem(iMenuPosition + 2), "");
  }


}// Loop

/*
  Drain serial/USB into the MIDI queue, then process queued events in order (FIFO, up to 10).
  Every MIDI message (notes, CC, program change, pitch bend, realtime, etc.) is passed through
  solely according to routing settings; no message type is blocked except by routing.
*/
void readData(){
  checkMidiIn_1();
  checkMidiIn_2();
  checkMidiIn_USB();
  processMidiQueue();
}

// Process all queued MIDI events in order (FIFO). Each event is forwarded based on routing only.
void processMidiQueue() {
  QueuedMidiEvent ev;
  while (popMidiQueue(&ev)) {
    sendPacket(ev.source, &ev.pkt);
  }
}

void copyData(uint8_t *theArray, uint8_t pInPacket[]) {
  for (uint8_t i = 0; i < 3; i++) {
    theArray[i] = pInPacket[i];
  }
}

// True if this routing target sends to the given output (0=out1, 1=out2, 2=USB)
bool routingSendsToOutput(uint8_t routing, uint8_t outIndex) {
  if (routing == ROUTING_TO_NONE) return false;
  switch (routing) {
    case ROUTING_TO_1:  return outIndex == 0;
    case ROUTING_TO_2:  return outIndex == 1;
    case ROUTING_TO_3:  return outIndex == 2;
    case ROUTING_TO_12: return outIndex == 0 || outIndex == 1;
    case ROUTING_TO_13: return outIndex == 0 || outIndex == 2;
    case ROUTING_TO_23: return outIndex == 1 || outIndex == 2;
    case ROUTING_TO_123: return true;
    default: return false;
  }
}

// Return MIDI packet length by status (2 for program change/channel pressure, 3 for most, 1 for realtime).
static uint8_t getMidiPacketLen(uint8_t status) {
  uint8_t s = status & 0xF0;
  if (s == 0xC0 || s == 0xD0) return 2;  // program change, channel pressure
  if (s >= 0xF0) return 1;               // system / realtime
  return 3;                               // note on/off, aftertouch, CC, pitch bend
}

// Send packet to a single output (0=Serial1, 1=Serial2, 2=USB). Skip if p->drop.
void sendToOutput(uint8_t outIndex, MidiPacket *p) {
  if (p->drop) return;
  uint8_t status = p->data[0] & 0xF0;
  uint8_t len = getMidiPacketLen(status);
  flashLED(outIndex + 1);
  if (outIndex == 0) Serial1.write(p->data, len);
  else if (outIndex == 1) Serial2.write(p->data, len);
  else if (outIndex == 2) Midi.SendData(p->data, 0);
}

// FEATURE_GROUP_FILTER: BLOCK_NONE=pass all, BLOCK_CLOCK=drop clock/start/stop, FILTER_CLOCK=only pass clock/start/stop
void processClockFilter(MidiPacket *p, uint8_t outIndex) {
  uint8_t status = p->data[0];
  bool isRealtime = (status == MIDI_CLOCK) || (status == MIDI_START) || (status == MIDI_STOP);
  uint8_t f = settings.output[outIndex].clockFilter;
  if (f == BLOCK_NONE) return;
  if (f == BLOCK_CLOCK && isRealtime) { p->drop = true; return; }
  if (f == FILTER_CLOCK && !isRealtime) { p->drop = true; return; }
}

// Only pass through notes that fit the selected scale and root. Others: set p->drop = true.
// Implemented: SCALE_MAJOR and SCALE_MINOR (natural minor) for every root note (C through B).
void processScale(MidiPacket *p, uint8_t outIndex) {
  uint8_t status = p->data[0] & 0xF0;
  if (status != 0x80 && status != 0x90) return; // only filter note on/off

  uint8_t scale = settings.output[outIndex].scale;
  uint8_t root = settings.output[outIndex].rootNote;
  if (scale == SCALE_PASSTHRU || root == ROOTNOTE_PASSTHROUGH) return;
  if (root < ROOTNOTE_C || root > ROOTNOTE_H) return; // invalid root

  // Root note enum 1..12 (C..B) -> pitch class 0..11
  uint8_t rootPc = root - 1;

  // Intervals in semitones from root: major 0,2,4,5,7,9,11 ; natural minor 0,2,3,5,7,8,10 ; pentatonic 5 notes
  static const uint8_t majorIntervals[]   = { 0, 2, 4, 5, 7, 9, 11 };
  static const uint8_t minorIntervals[]   = { 0, 2, 3, 5, 7, 8, 10 };
  static const uint8_t pentaMajorIntervals[] = { 0, 2, 4, 7, 9 };
  static const uint8_t pentaMinorIntervals[] = { 0, 3, 5, 7, 10 };

  const uint8_t *intervals;
  uint8_t nNotes = 7;
  if (scale == SCALE_MAJOR) {
    intervals = majorIntervals;
  } else if (scale == SCALE_MINOR) {
    intervals = minorIntervals;
  } else if (scale == SCALE_PENTATONIC_MAJOR) {
    intervals = pentaMajorIntervals;
    nNotes = 5;
  } else if (scale == SCALE_PENTATONIC_MINOR) {
    intervals = pentaMinorIntervals;
    nNotes = 5;
  } else {
    return;
  }

  uint8_t pc = p->data[1] % 12;
  bool inScale = false;
  for (uint8_t i = 0; i < nNotes; i++) {
    if ((rootPc + intervals[i]) % 12 == pc) { inScale = true; break; }
  }
  if (!inScale) p->drop = true;
}

void processVelocity(uint8_t *midiPacket, uint8_t outIndex){
  uint8_t iStatus = midiPacket[0] & 0xF0;
  if ((iStatus != 0x80) && (iStatus != 0x90)) return; // Nur midi noten
  // Note OFF (0x80): always send velocity 0 so it stays a note off
  if ((iStatus == 0x80)||(midiPacket[2]==0)) {
    midiPacket[2] = 0;
    return;
  }
  // Note ON (0x90): apply velocity setting
  uint8_t v = settings.output[outIndex].velocity;
  switch (v) {
    case VELOCITY_FIX_63:   midiPacket[2] = 63; break;
    case VELOCITY_FIX_100:  midiPacket[2] = 100; break;
    case VELOCITY_FIX_127:  midiPacket[2] = 127; break;
    case VELOCITY_RANDOM:   midiPacket[2] = random(128); break;
    case VELOCITY_RANDOM_100: midiPacket[2] = 91 + random(20); break;
    default: break; // VELOCITY_PASSTHRU
  }
}

void process_Note_Channel(uint8_t *midiPacket, uint8_t outIndex){
  uint8_t iStatus = midiPacket[0] & 0xF0;
  if ((iStatus != 0x80) && (iStatus != 0x90)) return; // Nur midi noten
  if (settings.output[outIndex].noteChannel != CHANNEL_PASSTHRU) {
    midiPacket[0] = (midiPacket[0] & 0xF0) + settings.output[outIndex].noteChannel - 1;
  }
}

void process_CC_Channel(uint8_t *midiPacket, uint8_t outIndex){
  if ((midiPacket[0] & 0xF0) != 0xB0) return; // Nur midi CCs
  if (settings.output[outIndex].ccChannel != CHANNEL_PASSTHRU) {
    midiPacket[0] = (midiPacket[0] & 0xF0) + settings.output[outIndex].ccChannel - 1;
  }
}
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

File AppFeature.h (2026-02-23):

// MenuItem.h
#ifndef AppFeature_h
#define AppFeature_h

#include <Arduino.h>

const uint8_t FEATURE_GROUP_PLACEHOLDER = 0;
const uint8_t FEATURE_GROUP_VELOCITY = 1;
const uint8_t FEATURE_GROUP_SCALE = 2;
const uint8_t FEATURE_GROUP_ROOTNOTE = 4;
const uint8_t FEATURE_GROUP_NOTE_CHANNEL = 8;
const uint8_t FEATURE_GROUP_CC_CHANNEL = 16;
const uint8_t FEATURE_GROUP_SCALE_HANDLER = 32;
const uint8_t FEATURE_GROUP_FILTER = 65;   // distinct from routing (32,64,128): clock block/pass per output
//
const uint8_t FEATURE_GROUP_ROUTING_IN_1 = 32;
const uint8_t FEATURE_GROUP_ROUTING_IN_2 = 64;
const uint8_t FEATURE_GROUP_ROUTING_IN_3 = 128;

const uint8_t ROUTING_TO_NONE = 0;
const uint8_t ROUTING_TO_1 = 1;
const uint8_t ROUTING_TO_2 = 2;
const uint8_t ROUTING_TO_3 = 3;
const uint8_t ROUTING_TO_12 = 4;
const uint8_t ROUTING_TO_13 = 5;
const uint8_t ROUTING_TO_23 = 6;
const uint8_t ROUTING_TO_123 = 7;
/*
const uint8_t ROUTING_2_TO_NONE = 0;
const uint8_t ROUTING_2_TO_1 = 1;
const uint8_t ROUTING_2_TO_2 = 2;
const uint8_t ROUTING_2_TO_3 = 3;
const uint8_t ROUTING_2_TO_12 = 4;
const uint8_t ROUTING_2_TO_13 = 5;
const uint8_t ROUTING_2_TO_23 = 6;
const uint8_t ROUTING_2_TO_123 = 7;

const uint8_t ROUTING_3_TO_NONE = 0;
const uint8_t ROUTING_3_TO_1 = 1;
const uint8_t ROUTING_3_TO_2 = 2;
const uint8_t ROUTING_3_TO_3 = 4;
const uint8_t ROUTING_3_TO_12 = 3;
const uint8_t ROUTING_3_TO_13 = 5;
const uint8_t ROUTING_3_TO_23 = 6;
const uint8_t ROUTING_3_TO_123 = 7;
*/

const uint8_t VELOCITY_PASSTHRU = 0;
const uint8_t VELOCITY_FIX_63 = 1;
const uint8_t VELOCITY_FIX_100 = 2;
const uint8_t VELOCITY_RANDOM_100 = 3;
const uint8_t VELOCITY_FIX_127 = 4;
const uint8_t VELOCITY_RANDOM = 5;

const uint8_t SCALE_PASSTHRU = 0;
const uint8_t SCALE_MAJOR = 1;
const uint8_t SCALE_MINOR = 2;
const uint8_t SCALE_PENTATONIC_MAJOR = 3;
const uint8_t SCALE_PENTATONIC_MINOR = 4;

const uint8_t SCALE_HANDLER_FILTER = 0;
const uint8_t SCALE_HANDLER_MAPPER = 1;

const uint8_t ROOTNOTE_PASSTHROUGH = 0;
const uint8_t ROOTNOTE_C = 01;
const uint8_t ROOTNOTE_Cs = 2;
const uint8_t ROOTNOTE_D = 3;
const uint8_t ROOTNOTE_Ds = 4;
const uint8_t ROOTNOTE_E = 5;
const uint8_t ROOTNOTE_F = 6;
const uint8_t ROOTNOTE_Fs = 7;
const uint8_t ROOTNOTE_G = 8;
const uint8_t ROOTNOTE_Gs = 9;
const uint8_t ROOTNOTE_A = 10;
const uint8_t ROOTNOTE_As = 11;
const uint8_t ROOTNOTE_H = 12;


const uint8_t CHANNEL_PASSTHRU = 0;
const uint8_t CHANNEL_1 = 1;
const uint8_t CHANNEL_2 = 2;
const uint8_t CHANNEL_3 = 3;
const uint8_t CHANNEL_4 = 4;
const uint8_t CHANNEL_5 = 5;
const uint8_t CHANNEL_6 = 6;
const uint8_t CHANNEL_7 = 7;
const uint8_t CHANNEL_8 = 8;
const uint8_t CHANNEL_9 = 9;
const uint8_t CHANNEL_10 = 10;
const uint8_t CHANNEL_11 = 11;
const uint8_t CHANNEL_12 = 12;
const uint8_t CHANNEL_13 = 13;
const uint8_t CHANNEL_14 = 14;
const uint8_t CHANNEL_15 = 15;
const uint8_t CHANNEL_16 = 16;

const uint8_t BLOCK_NONE = 1;
const uint8_t BLOCK_CLOCK = 2;  
const uint8_t FILTER_CLOCK = 3; // Only let CLOCK, START and STOP pass through

class AppFeature {

  private:
    uint8_t iFeature = -1;
    //uint8_t iOutport = -1;
    uint8_t iFeatureGroup = -1;
    bool bSelected = false;
    String sText;
    uint8_t iOutport;
    

  public:
    AppFeature(String pText, uint8_t pOutport, uint8_t pFeatureGroup, uint8_t pFeature);
    AppFeature(String pText, uint8_t pOutport, uint8_t pFeatureGroup, uint8_t pFeature, bool pSelect);
    uint8_t getFeatureGroup();
    uint8_t getFeature();
    String getText();
    void select(bool p);
    bool isSelected();
    uint8_t getOutport();

};

#endif

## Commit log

2026-02-22 fix bug when scale was set and velocity!=passthru
    [esp32-midi-processor.ino]
2026-02-22 bugfix: send note off on incoming note off
    [esp32-midi-processor.ino]
2026-02-22 add usb send, fix 0-velocity-handling
    [esp32-midi-processor.ino]
2026-02-25 manually retry usb init when buttons a and d are pressed for 3 seconds
2026-03-05 add 3mf file
    [esp32 Midi Processor.3mf]
2026-03-30 add kicad files
    [esp32-midi-processor.kicad_pcb, esp32-midi-processor.kicad_sch]
2026-04-05 add reviewed BOM
    [BOM Rev2.ods]
2026-04-05 add link to pcbway in readme
